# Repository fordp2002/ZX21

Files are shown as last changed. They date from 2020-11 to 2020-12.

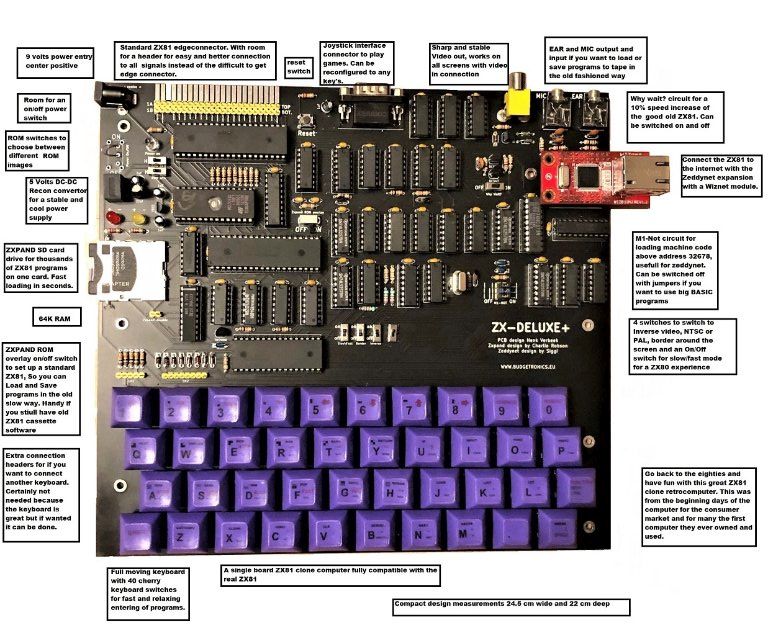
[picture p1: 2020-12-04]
Datasheets/Misc/zxdeluxe metb tekst klein formaat.jpg

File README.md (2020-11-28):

# ZX21
40 Years after the Sinclair ZX81 was released this project aims to preserve the first 4 chip computer

This a computer presevation project for the [Sinclair ZX81](https://github.com/fordp2002/ZX21.git).

Features (Hopefully).

* Drop in replacement for a ZX81
* Built in 16K+ RAM, no need for a RAM Pack
* Built in Composite Video Output 
* Barrel Jack power input, center Positive
* OPTION: Single Joystick port (not compatible with quickfire etc.)
* OPTION: Switchable to 1K RAM
* OPTION: [Back Porch Support](http://zx.zigg.net/misc-projects/ZX81_Video_Conditioning.pdf) for early ULAs
* OPTION: Built in support for [ZX-Wespi](https://github.com/holmatic/zx-iot-mi)
* OPTION: [ZON-X](http://www.zx81stuff.org.uk/zx81/hardware/ZONX81) Compatible Yamaha YM2149F Based Sound
* OPTION: Switchable between Sinclair ROM OR [AT28C256 EEPROM](http://ww1.microchip.com/downloads/en/DeviceDoc/doc0006.pdf)
* OPTION: 16 Pin Box Header for DK'Tronics Keyboard

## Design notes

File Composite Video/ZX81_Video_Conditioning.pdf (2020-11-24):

ZX81 Video Conditioning | http://zx.zigg.net

# ZX81 Video Conditioning

# 1. Introduction

Presented below are two electronic circuits that can be used to improve the video output of the ZX81 ULA, in particular those that do not generate a period of black level voltage (the back porch) following each line synchronisation pulse.

### This document complements a video presentation, in which the operation of each circuit is

described. A link to this video can be found at http://zx.zigg.net.

# 2. All Discrete Transistor Circuit

## 2.1. Circuit Diagram

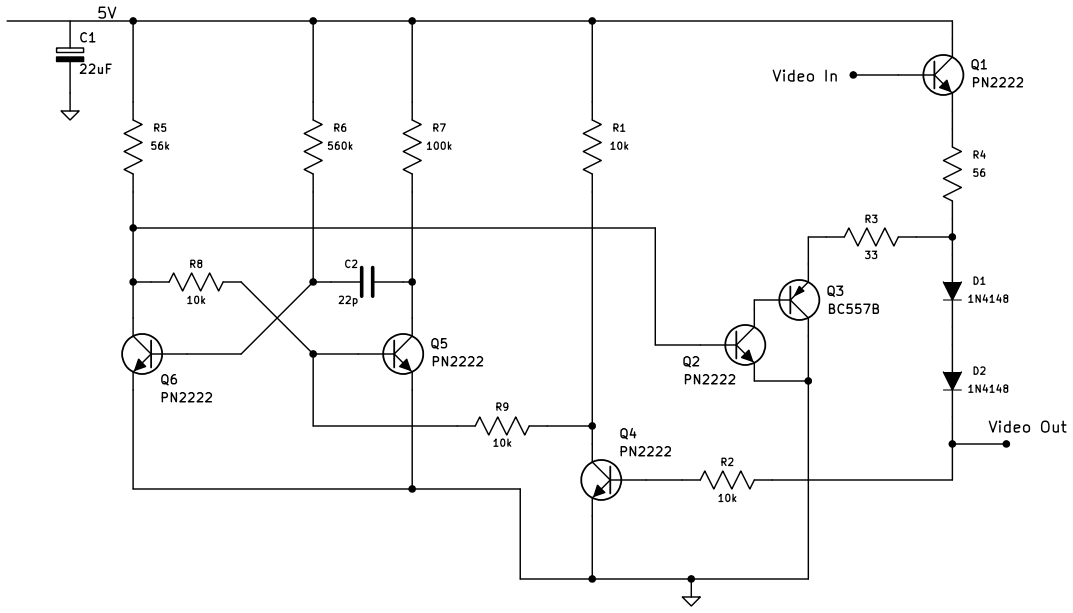
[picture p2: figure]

© Copyright 2015 Ziggurat Communications Ltd. | Version 1.0 | Page 1

# 3. 555-Based Circuit

## 3.1. Circuit Diagram

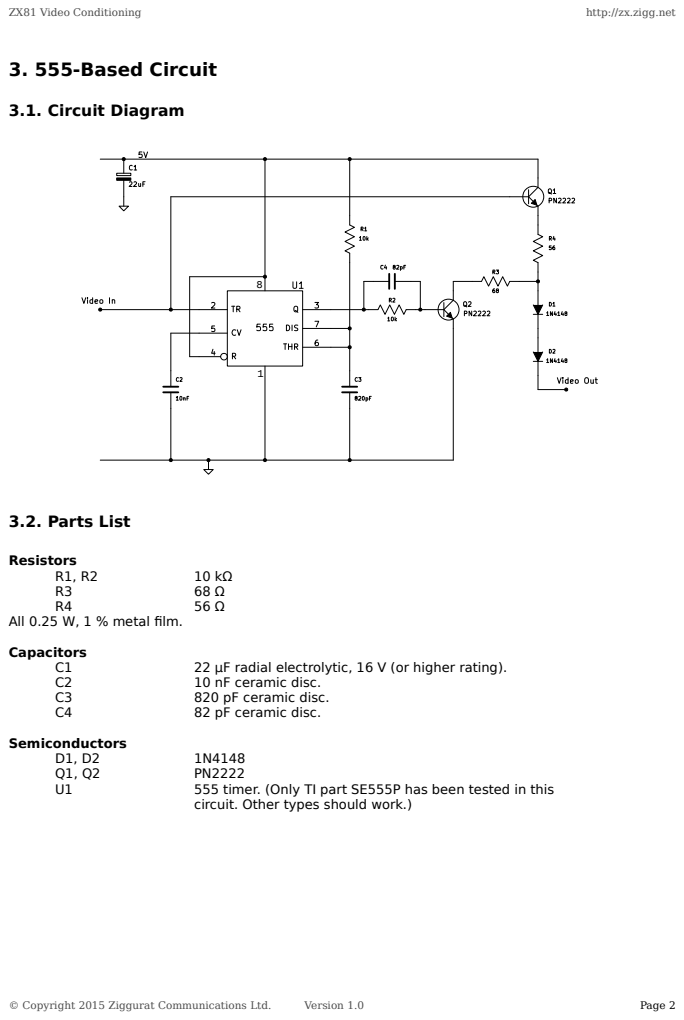
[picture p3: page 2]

circuit. Other types should work.)

## 3.3. Stripboard Layout

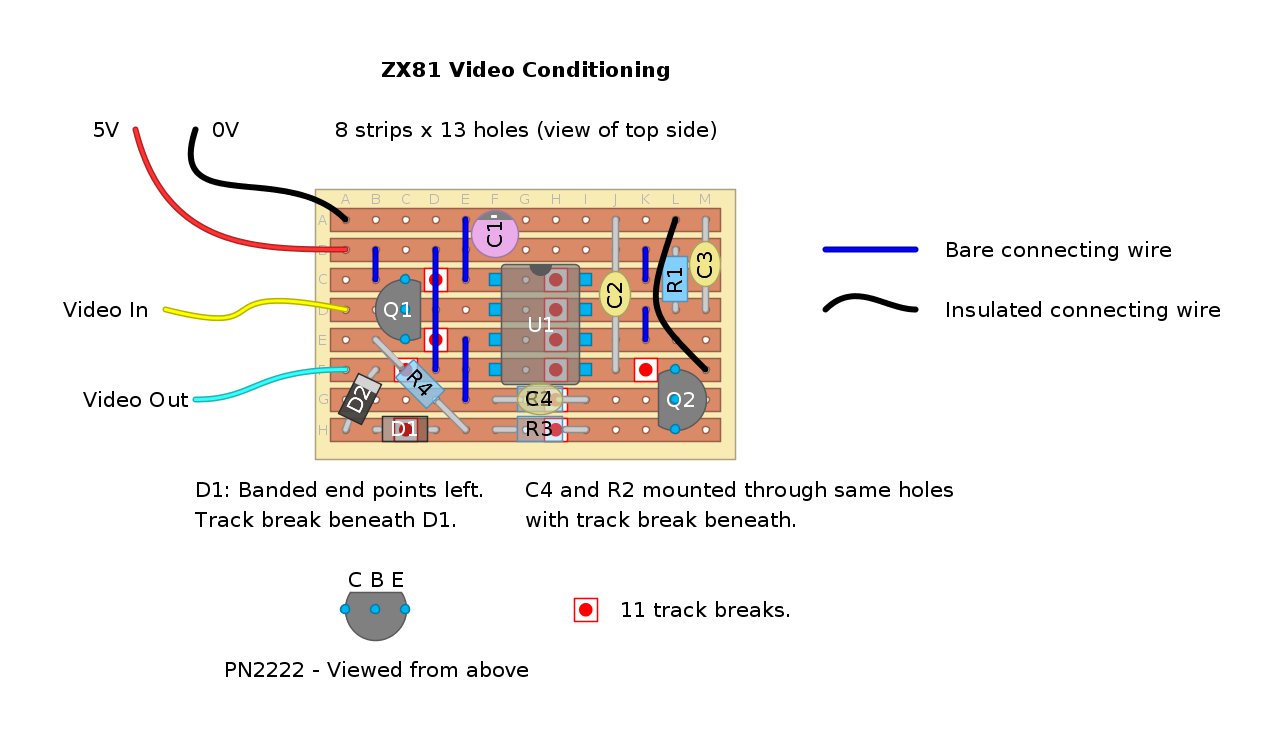
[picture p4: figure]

### CAUTION: The pin-out of most PN2222 transistors is as shown above. However, some have the

positions of their collector and emitter swapped.

The stripboard layout graphic was created using DIY Layout Creator (DIYLC).

This document © Copyright 2015 Ziggurat Communications Ltd. This document may be freely copied, distributed and modified provided this copyright notice is not removed. Modified versions must clearly indicate they have been modified. Portions of this document may be used in other works provided the portions are clearly attributed to Ziggurat Communications Ltd or/and http://zx.zigg.net. This notice does not apply to any elements of this document not created by Ziggurat Communications Ltd.

© Copyright 2015 Ziggurat Communications Ltd. | Version 1.0 | Page 3

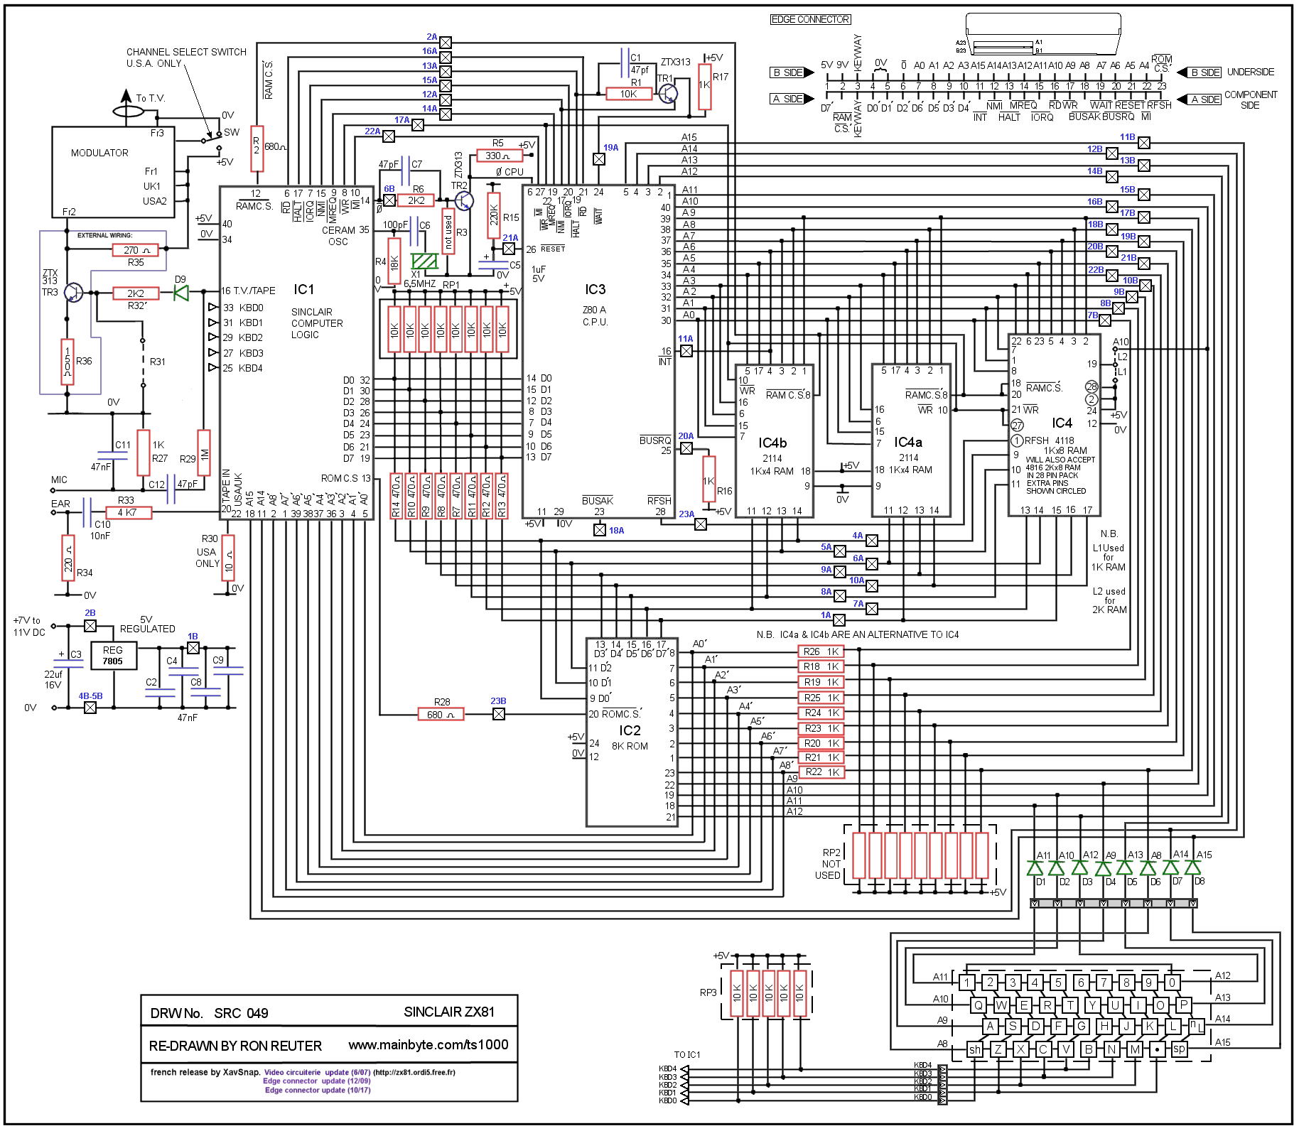
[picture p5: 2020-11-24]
Schematic/schema_ZX81_Fr.gif

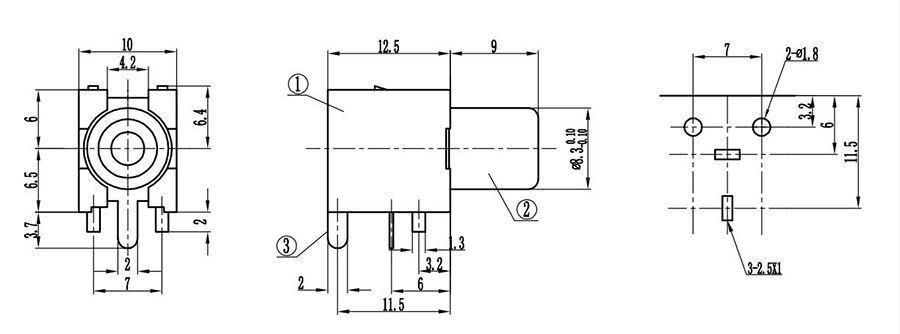
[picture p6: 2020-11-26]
Schematic/Yellow RCA Socket.jpg

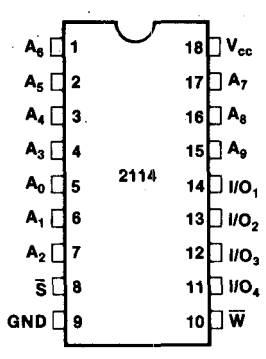
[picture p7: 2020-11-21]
Datasheets/RAM/2114 SRAM pin-out.png

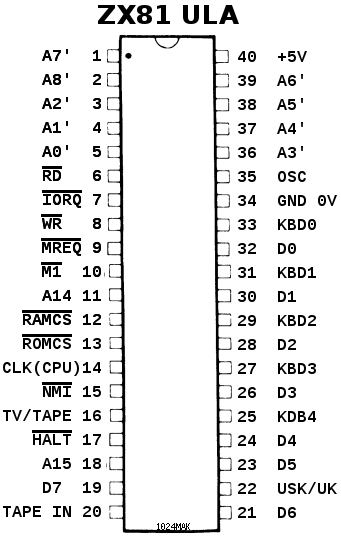
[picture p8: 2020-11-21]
Datasheets/ULA/ZX81 ULA.png

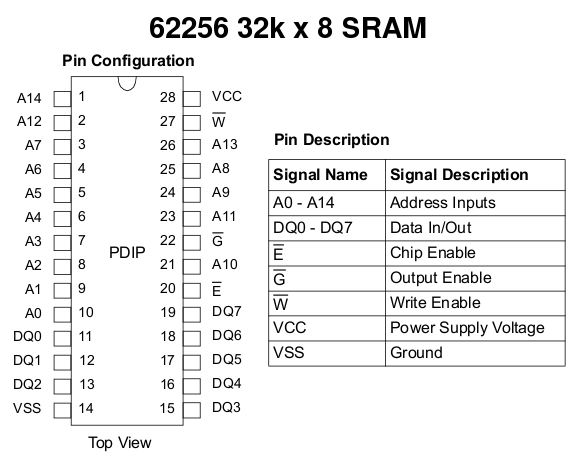
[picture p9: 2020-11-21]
Datasheets/RAM/62256 32k SRAM pin-out.png

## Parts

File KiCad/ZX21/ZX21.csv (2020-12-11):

Id | Designator | Package | Quantity | Designation | Supplier and ref
1 | REF*** | OSHW-Logo2_7.3x6mm_SilkScreen | 1 | OSHW-Logo2_7.3x6mm_SilkScreen
2 | REF*** | OSHW-Logo2_7.3x6mm_Copper | 1 | OSHW-Logo2_7.3x6mm_Copper
3 | MIC1,EAR1 | ASJ_125_3_3.5mm_Jack | 2 | Audio-Jack-3
4 | C101,C302 | CP_Radial_D5.0mm_P2.50mm | 2 | 22U
5 | IC301 | TO-220-3_Vertical | 1 | 3V3 PSU
6 | C303 | C_0603_HandSoldering | 1 | 10N
7 | X1 | Resonator-3pin_w7.0mm_h2.5mm | 1 | 3.5MHz
8 | J701 | Pin_Header_Straight_2x23_Pitch2.54mm | 1 | Conn_02x23_Row_Letter_First
9 | REF** | MountingHole_2.7mm | 1 | MountingHole_2.7mm
10 | J302,J204,J203,J101 | Pin_Header_Straight_1x03_Pitch2.54mm | 4 | Conn_01x03
11 | S1 | EG4208 | 1 | EG4208A
12 | J504,J503,J502 | Pin_Header_Straight_1x08_Pitch2.54mm | 3 | Conn_01x08
13 | C301 | CP_Radial_D5.0mm_P2.50mm | 1 | 47U 25V
14 | C5 | CP_Radial_D5.0mm_P2.50mm | 1 | 1U
15 | C3 | CP_Axial_L11.0mm_D5.0mm_P18.00mm_Horizontal | 1 | 22uF
16 | C501,C9,C4 | C_Disc_D4.7mm_W2.5mm_P5.00mm | 3 | 100N
17 | C104 | C_Disc_D4.7mm_W2.5mm_P5.00mm | 1 | 82P
18 | C103 | C_Disc_D4.7mm_W2.5mm_P5.00mm | 1 | 820P
19 | C102,C10,C8 | C_Disc_D4.7mm_W2.5mm_P5.00mm | 3 | 10N
20 | C12,C7 | C_Disc_D4.7mm_W2.5mm_P5.00mm | 2 | 47P
21 | C11 | C_Disc_D4.7mm_W2.5mm_P5.00mm | 1 | 47N
22 | C6 | C_Disc_D4.7mm_W2.5mm_P5.00mm | 1 | 100P
23 | C1 | C_Disc_D3.0mm_W2.0mm_P2.50mm | 1 | 47P
24 | R504,R301,R201,R27,R26,R25,R24,R23,R22,R21,R20,R19,R18,R17,R16 | R_Axial_DIN0204_L3.6mm_D1.6mm_P7.62mm_Horizontal | 15 | 1K
25 | R503,R502,R501,R302,R33 | R_Axial_DIN0204_L3.6mm_D1.6mm_P7.62mm_Horizontal | 5 | 4K7
26 | R401,R102,R101,R1 | R_Axial_DIN0204_L3.6mm_D1.6mm_P7.62mm_Horizontal | 4 | 10K
27 | R303 | R_Axial_DIN0204_L3.6mm_D1.6mm_P7.62mm_Horizontal | 1 | 100R
28 | IC801 | DIP-4_W15.24mm_Socket_LongPads | 1 | AS6C4008Extra
29 | D102,D101,D8,D7,D6,D5,D4,D3,D2,D1 | D_DO-35_SOD27_P7.62mm_Horizontal | 10 | 1N4148
30 | R104 | R_Axial_DIN0204_L3.6mm_D1.6mm_P7.62mm_Horizontal | 1 | 56R
31 | R103 | R_Axial_DIN0204_L3.6mm_D1.6mm_P7.62mm_Horizontal | 1 | 68R
32 | R34 | R_Axial_DIN0204_L3.6mm_D1.6mm_P7.62mm_Horizontal | 1 | 220R
33 | R30 | R_Axial_DIN0204_L3.6mm_D1.6mm_P7.62mm_Horizontal | 1 | 10R
34 | R29 | R_Axial_DIN0204_L3.6mm_D1.6mm_P7.62mm_Horizontal | 1 | 1M
35 | R28,R2 | R_Axial_DIN0204_L3.6mm_D1.6mm_P7.62mm_Horizontal | 2 | 680R
36 | R15 | R_Axial_DIN0204_L3.6mm_D1.6mm_P7.62mm_Horizontal | 1 | 220K
37 | R14,R13,R12,R11,R10,R9,R8,R7 | R_Axial_DIN0204_L3.6mm_D1.6mm_P7.62mm_Horizontal | 8 | 470R
38 | R6 | R_Axial_DIN0204_L3.6mm_D1.6mm_P7.62mm_Horizontal | 1 | 2K2
39 | R5 | R_Axial_DIN0204_L3.6mm_D1.6mm_P7.62mm_Horizontal | 1 | 330R
40 | R4 | R_Axial_DIN0204_L3.6mm_D1.6mm_P7.62mm_Horizontal | 1 | 18K
41 | IC503 | DIP-16_W7.62mm_Socket_LongPads | 1 | YMZ284
42 | IC4 | DIP-28_W15.24mm_Socket_LongPads | 1 | 62256
43 | R106,R105 | R_0603_HandSoldering | 2 | 10K
44 | IC501 | DIP-40_W15.24mm_Socket_LongPads | 1 | YM2149
45 | IC3 | DIP-40_W15.24mm_Socket_LongPads | 1 | Z80A
46 | IC1 | DIP-40_W15.24mm_Socket_LongPads | 1 | ULA 2C210E
47 | IC2 | DIP-28_W15.24mm_Socket_LongPads | 1 | AT28C256
48 | IC303 | SOT-23_Handsoldering | 1 | AZ1117-3.3
49 | IC502 | DIP-20_W7.62mm_Socket_LongPads | 1 | GAL16V8
50 | J501 | Pin_Header_Straight_1x06_Pitch2.54mm | 1 | Conn_01x06
51 | REF**,REF**,REF**,REF**,REF** | MountingHole_3mm | 5 | MountingHole_3mm
52 | C105 | C_0603_HandSoldering | 1 | 100N
53 | IC102 | SOIC-14_3.9x8.7mm_Pitch1.27mm | 1 | 74HCT00
54 | IC302 | ESP32-WROOM | 1 | ESP32-WROOM
55 | C2 | C_Disc_D5.0mm_W2.5mm_P2.50mm | 1 | 100N
56 | EDGE1 | ZX_Bus_Edge_Connector | 1 | ZX81BUS
57 | IC101 | DIP-8_W7.62mm_Socket_LongPads | 1 | 555
58 | J1 | BARREL_JACK | 1 | Jack-DC
59 | J301 | Pin_Header_Straight_1x04_Pitch2.54mm | 1 | Conn_01x04
60 | J401 | DB9MC | 1 | DB9_Male
61 | J601 | IDC_Header_Straight_16pins | 1 | Conn_02x08_Odd_Even
62 | J702,J703 | Pin_Header_Straight_1x09_Pitch2.54mm | 2 | Conn_01x09
63 | KB1 | Pin_Header_Straight_1x05_Pitch2.54mm | 1 | Conn_01x05
64 | KB2 | Pin_Header_Straight_1x08_Pitch2.54mm | 1 | Conn_01x08
65 | TR403,TR401,TR402,TR404,TR405 | TO-92_Molded_Narrow | 5 | 2N3904
66 | REG1 | TO-220-3_Horizontal | 1 | L7805
67 | RP1 | R_Array_SIP9 | 1 | 10K
68 | RP3 | R_Array_SIP6 | 1 | 10K
69 | TR1,TR2 | TO-92_Molded_Narrow | 2 | BC548
70 | TR101,TR102 | TO-92_Molded_Narrow | 2 | PN2222
71 | VIDEO1 | YELLOW_RCA | 1 | CVBS

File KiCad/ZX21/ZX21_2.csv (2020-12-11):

Reference | Quantity | Value | Footprint | Datasheet | Description | Height | Manufacturer_Name | Manufacturer_Part_Number | Mouser Part Number | Mouser Price/Stock
C1 | 1 | 47P | Capacitors_THT:C_Disc_D3.0mm_W2.0mm_P2.50mm
C8 C10 C102 | 3 | 10N | Capacitors_ThroughHole:C_Disc_D4.7mm_W2.5mm_P5.00mm
C101 C302 | 2 | 22U | Capacitors_ThroughHole:CP_Radial_D5.0mm_P2.50mm
C103 | 1 | 820P | Capacitors_ThroughHole:C_Disc_D4.7mm_W2.5mm_P5.00mm
C104 | 1 | 82P | Capacitors_ThroughHole:C_Disc_D4.7mm_W2.5mm_P5.00mm
C105 | 1 | 100N | Capacitors_SMD:C_0603_HandSoldering
C11 | 1 | 47N | Capacitors_ThroughHole:C_Disc_D4.7mm_W2.5mm_P5.00mm
C2 | 1 | 100N | Capacitors_THT:C_Disc_D5.0mm_W2.5mm_P2.50mm
C3 | 1 | 22uF | Capacitors_ThroughHole:CP_Axial_L11.0mm_D5.0mm_P18.00mm_Horizontal
C301 | 1 | 47U 25V | Capacitors_ThroughHole:CP_Radial_D5.0mm_P2.50mm
C303 | 1 | 10N | Capacitors_SMD:C_0603_HandSoldering
C5 | 1 | 1U | Capacitors_ThroughHole:CP_Radial_D5.0mm_P2.50mm
C6 | 1 | 100P | Capacitors_ThroughHole:C_Disc_D4.7mm_W2.5mm_P5.00mm
C7 C12 | 2 | 47P | Capacitors_ThroughHole:C_Disc_D4.7mm_W2.5mm_P5.00mm
C4 C9 C501 | 3 | 100N | Capacitors_ThroughHole:C_Disc_D4.7mm_W2.5mm_P5.00mm
D1 D2 D3 D4 D5 D6 D7 D8 D101 D102 | 10 | 1N4148 | zxbus:D_DO-35_SOD27_P7.62mm_Horizontal | http://www.nxp.com/documents/data_sheet/1N4148_1N4448.pdf
EDGE1 | 1 | ZX81BUS | zxbus:ZX_Bus_Edge_Connector
IC1 | 1 | ULA 2C210E | zxbus:DIP-40_W15.24mm_Socket_LongPads
IC101 | 1 | 555 | Housings_DIP:DIP-8_W7.62mm_Socket_LongPads | http://www.ti.com/lit/ds/symlink/tlc555.pdf
IC102 | 1 | 74HCT00 | Housings_SOIC:SOIC-14_3.9x8.7mm_Pitch1.27mm | http://www.ti.com/lit/gpn/sn74hct00
IC2 | 1 | AT28C256 | zxbus:DIP-28_W15.24mm_Socket_LongPads
IC3 | 1 | Z80A | zxbus:DIP-40_W15.24mm_Socket_LongPads | www.zilog.com/manage_directlink.php?filepath=docs/z80/um0080
IC301 | 1 | 3V3 PSU | TO_SOT_Packages_THT:TO-220-3_Vertical | http://www.st.com/content/ccc/resource/technical/document/datasheet/41/4f/b3/b0/12/d4/47/88/CD00000444.pdf/files/CD00000444.pdf/jcr:content/translations/en.CD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
IC302 | 1 | ESP32-WROOM | ESP32-footprints-Lib:ESP32-WROOM
IC303 | 1 | AZ1117-3.3 | TO_SOT_Packages_SMD:SOT-23_Handsoldering | https://www.diodes.com/assets/Datasheets/AZ1117.pdf
IC4 | 1 | 62256 | zxbus:DIP-28_W15.24mm_Socket_LongPads
IC501 | 1 | YM2149 | zxbus:DIP-40_W15.24mm_Socket_LongPads
IC502 | 1 | GAL16V8 | Housings_DIP:DIP-20_W7.62mm_Socket_LongPads
IC503 | 1 | YMZ284 | Housings_DIP:DIP-16_W7.62mm_Socket_LongPads
IC801 | 1 | AS6C4008Extra | zxbus:DIP-4_W15.24mm_Socket_LongPads
J1 | 1 | Jack-DC | Connect:BARREL_JACK | ~
J101 J203 J204 J302 | 4 | Conn_01x03 | zxbus:Pin_Header_Straight_1x03_Pitch2.54mm | ~
J301 | 1 | Conn_01x04 | Pin_Headers:Pin_Header_Straight_1x04_Pitch2.54mm | ~
J401 | 1 | DB9_Male | Connectors:DB9MC
J501 | 1 | Conn_01x06 | Pin_Headers:Pin_Header_Straight_1x06_Pitch2.54mm | ~
J502 J503 J504 | 3 | Conn_01x08 | zxbus:Pin_Header_Straight_1x08_Pitch2.54mm | ~
J601 | 1 | Conn_02x08_Odd_Even | Connectors:IDC_Header_Straight_16pins | ~
J701 | 1 | Conn_02x23_Row_Letter_First | zxbus:Pin_Header_Straight_2x23_Pitch2.54mm | ~
J702 J703 | 2 | Conn_01x09 | Pin_Headers:Pin_Header_Straight_1x09_Pitch2.54mm | ~
KB1 | 1 | Conn_01x05 | Pin_Headers:Pin_Header_Straight_1x05_Pitch2.54mm | ~
KB2 | 1 | Conn_01x08 | Pin_Headers:Pin_Header_Straight_1x08_Pitch2.54mm | ~
MIC1 EAR1 | 2 | Audio-Jack-3 | zxbus:ASJ_125_3_3.5mm_Jack | ~
R1 R101 R102 R401 | 4 | 10K | Resistors_ThroughHole:R_Axial_DIN0204_L3.6mm_D1.6mm_P7.62mm_Horizontal
R7 R8 R9 R10 R11 R12 R13 R14 | 8 | 470R | Resistors_ThroughHole:R_Axial_DIN0204_L3.6mm_D1.6mm_P7.62mm_Horizontal
R103 | 1 | 68R | Resistors_ThroughHole:R_Axial_DIN0204_L3.6mm_D1.6mm_P7.62mm_Horizontal
R104 | 1 | 56R | Resistors_ThroughHole:R_Axial_DIN0204_L3.6mm_D1.6mm_P7.62mm_Horizontal
R105 R106 | 2 | 10K | Resistors_SMD:R_0603_HandSoldering
R15 | 1 | 220K | Resistors_ThroughHole:R_Axial_DIN0204_L3.6mm_D1.6mm_P7.62mm_Horizontal
R2 R28 | 2 | 680R | Resistors_ThroughHole:R_Axial_DIN0204_L3.6mm_D1.6mm_P7.62mm_Horizontal
R16 R17 R18 R19 R20 R21 R22 R23 R24 R25 R26 R27 R201 R301 R504 | 15 | 1K | Resistors_ThroughHole:R_Axial_DIN0204_L3.6mm_D1.6mm_P7.62mm_Horizontal
R29 | 1 | 1M | Resistors_ThroughHole:R_Axial_DIN0204_L3.6mm_D1.6mm_P7.62mm_Horizontal
R30 | 1 | 10R | Resistors_ThroughHole:R_Axial_DIN0204_L3.6mm_D1.6mm_P7.62mm_Horizontal
R303 | 1 | 100R | Resistors_ThroughHole:R_Axial_DIN0204_L3.6mm_D1.6mm_P7.62mm_Horizontal
R33 R302 R501 R502 R503 | 5 | 4K7 | Resistors_ThroughHole:R_Axial_DIN0204_L3.6mm_D1.6mm_P7.62mm_Horizontal
R34 | 1 | 220R | Resistors_ThroughHole:R_Axial_DIN0204_L3.6mm_D1.6mm_P7.62mm_Horizontal
R4 | 1 | 18K | Resistors_ThroughHole:R_Axial_DIN0204_L3.6mm_D1.6mm_P7.62mm_Horizontal
R5 | 1 | 330R | Resistors_ThroughHole:R_Axial_DIN0204_L3.6mm_D1.6mm_P7.62mm_Horizontal
R6 | 1 | 2K2 | Resistors_ThroughHole:R_Axial_DIN0204_L3.6mm_D1.6mm_P7.62mm_Horizontal
REG1 | 1 | L7805 | TO_SOT_Packages_THT:TO-220-3_Horizontal | http://www.st.com/content/ccc/resource/technical/document/datasheet/41/4f/b3/b0/12/d4/47/88/CD00000444.pdf/files/CD00000444.pdf/jcr:content/translations/en.CD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
RP1 | 1 | 10K | Resistors_THT:R_Array_SIP9 | http://www.vishay.com/docs/31509/csc.pdf
RP3 | 1 | 10K | Resistors_THT:R_Array_SIP6 | http://www.vishay.com/docs/31509/csc.pdf
S1 | 1 | EG4208A | SamacSys_Parts:EG4208 | https://www.e-switch.com/system/asset/product_line/data_sheet/119/EG.pdf | Slide Switches 4P2T SIDE OP PC MNT | 5 | E-Switch | EG4208A | 612-EG4208A | https://www.mouser.co.uk/ProductDetail/E-Switch/EG4208A?qs=01kh3H%252BlXijiZ%252BDtLjJDLw%3D%3D
TR101 TR102 | 2 | PN2222 | TO_SOT_Packages_THT:TO-92_Molded_Narrow | http://www.fairchildsemi.com/ds/PN/PN2222A.pdf
TR1 TR2 | 2 | BC548 | TO_SOT_Packages_THT:TO-92_Molded_Narrow | http://www.fairchildsemi.com/ds/BC/BC547.pdf
TR401 TR402 TR403 TR404 TR405 | 5 | 2N3904 | TO_SOT_Packages_THT:TO-92_Molded_Narrow | https://www.fairchildsemi.com/datasheets/2N/2N3904.pdf
VIDEO1 | 1 | CVBS | zxbus:YELLOW_RCA
X1 | 1 | 3.5MHz | Crystals:Resonator-3pin_w7.0mm_h2.5mm

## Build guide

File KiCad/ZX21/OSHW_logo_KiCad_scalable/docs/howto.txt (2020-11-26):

How to make your own:
---------------------

Watch / read this first:

* http://www.kicad-pcb.org/display/KICAD/Videos+by+zupnikal

The last two videos should be helpful for how to create a custom .emp file from images.

* http://www.re-innovation.co.uk/web12/index.php/en/blog-75/230-adding-logo-to-kicad

If you use linux (which you should), you don't have to use the online-scaler. Just use the scripts!

---

* Create a folder to hold your new footprint library.
* Copy the scripts 'make_lib.sh' and 'scale.pl' into that folder.
* Make sure these files are executable (chmod u+x ...).
* Copy your custom .emp file into that foler.

* Run the 'make_lib.sh' script as follows:

./make_lib.sh input-file.emp lib-name.mod START END

START and END are placeholders for positive integer numbers (1,2,3...) that determine
the range of created footprint sizes. The units are metric (mm).

The 'lib-name.mod' file will show up in the 'lib' sub-folder. Add it to your pcbnew
library settings as usual.

Footprints that are created for back-layers are automagically mirrored horizontally.
To place them onto a back-layer, hover the mouse-pointer over them and press 'f' for 'flip'.

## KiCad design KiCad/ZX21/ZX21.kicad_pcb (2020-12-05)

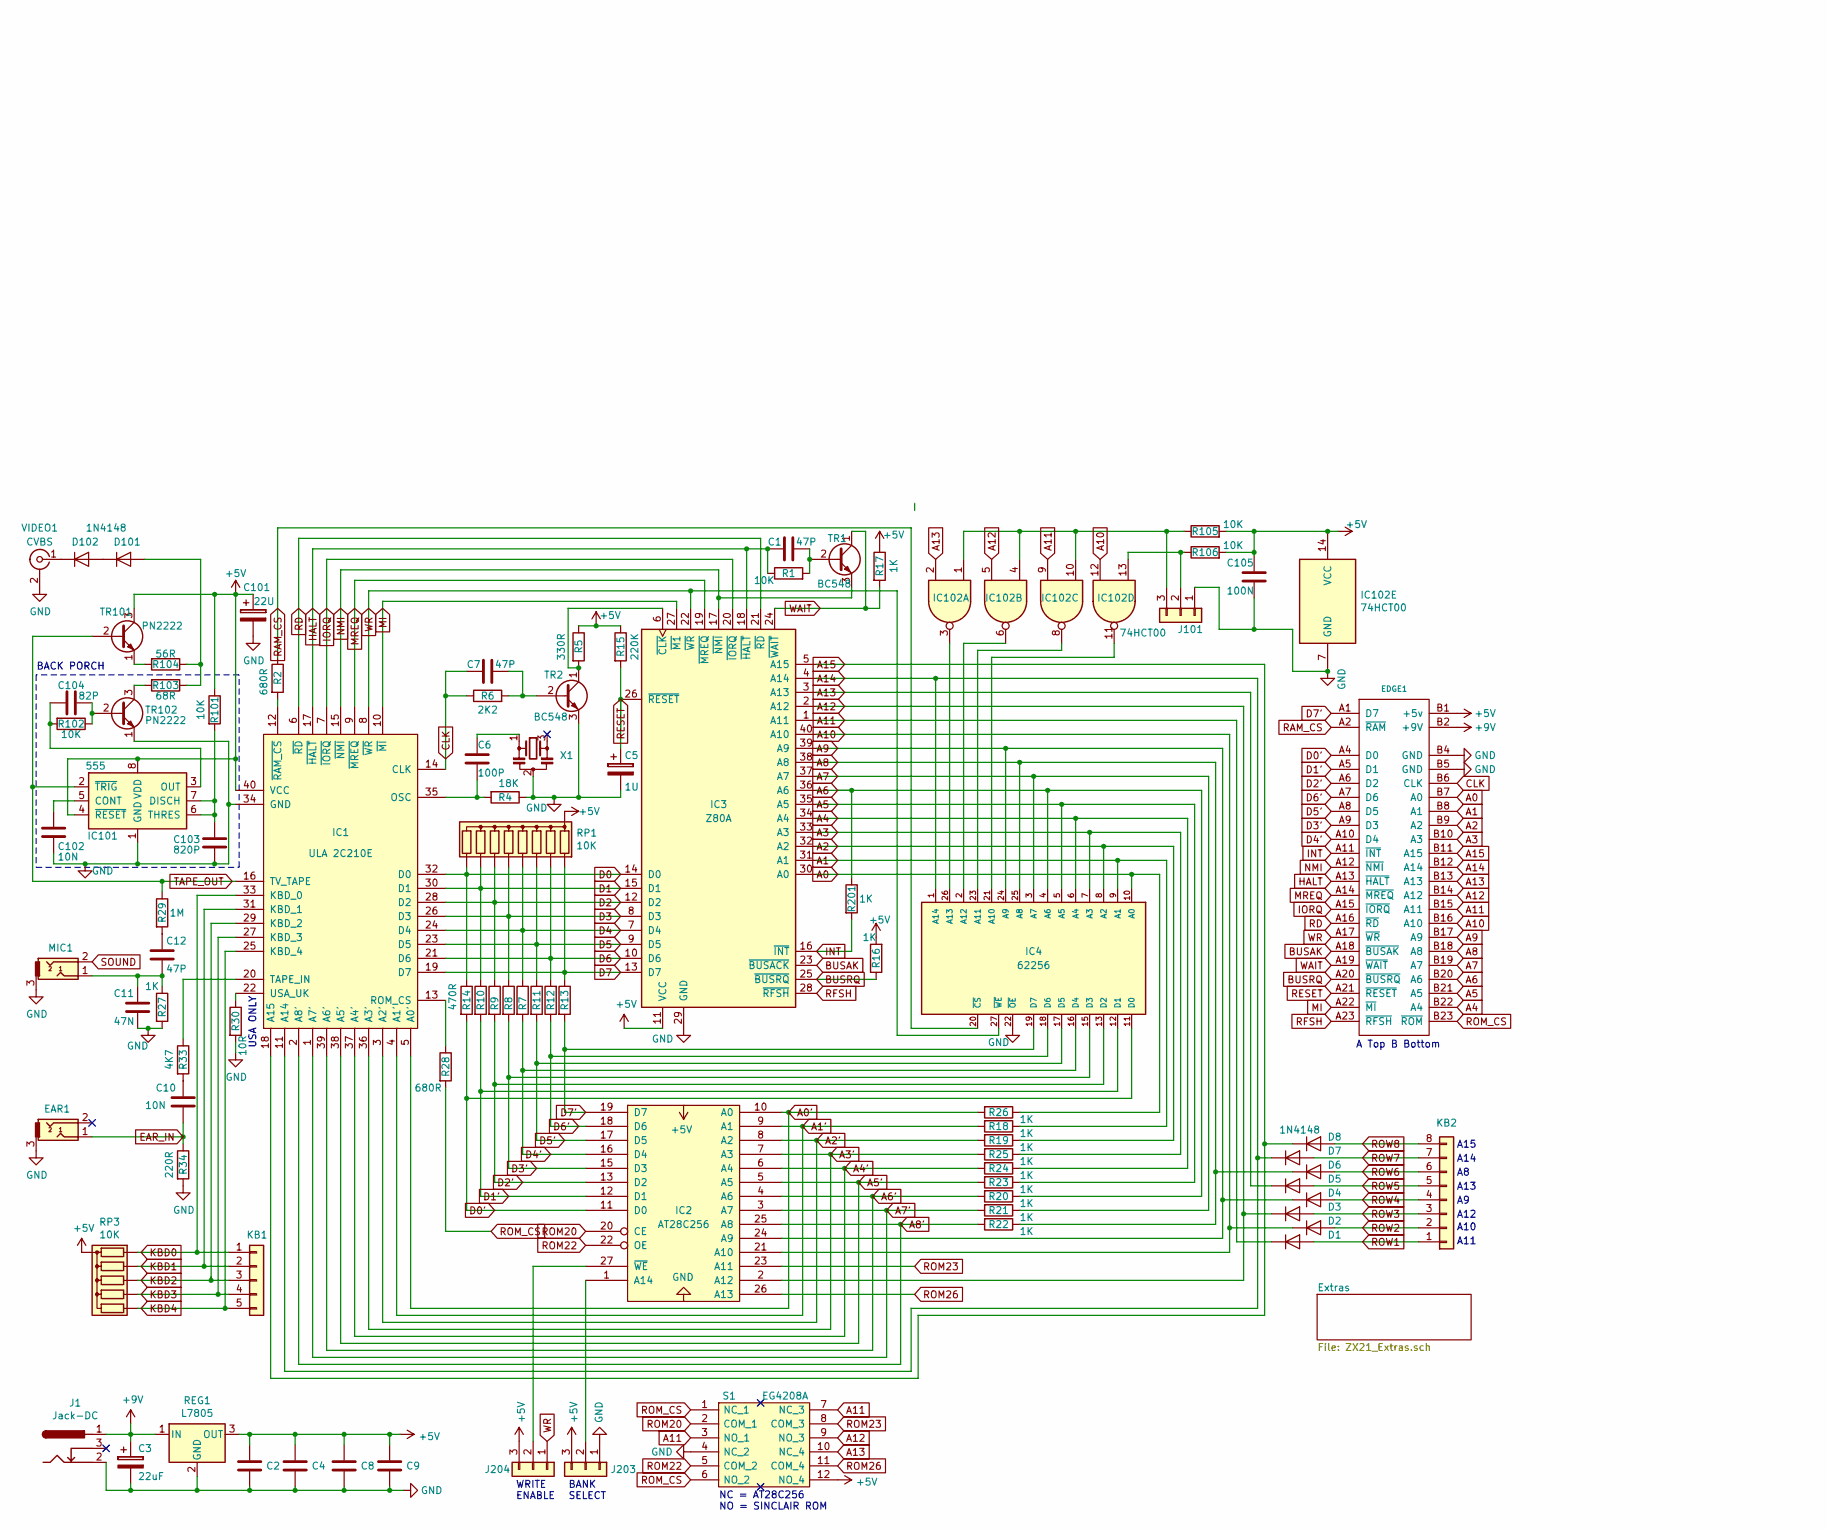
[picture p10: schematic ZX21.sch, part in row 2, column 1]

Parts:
C1: 47P; C_Disc_D3.0mm_W2.0mm_P2.50mm
C2: 100N; C_Disc_D5.0mm_W2.5mm_P2.50mm
C3: 22uF; CP_Axial_L11.0mm_D5.0mm_P18.00mm_Horizontal
C4, C9: 100N; C_Disc_D4.7mm_W2.5mm_P5.00mm
C5: 1U; CP_Radial_D5.0mm_P2.50mm
C6: 100P; C_Disc_D4.7mm_W2.5mm_P5.00mm
C7, C12: 47P; C_Disc_D4.7mm_W2.5mm_P5.00mm
C8, C10, C102: 10N; C_Disc_D4.7mm_W2.5mm_P5.00mm
C11: 47N; C_Disc_D4.7mm_W2.5mm_P5.00mm
C101: 22U; CP_Radial_D5.0mm_P2.50mm
C103: 820P; C_Disc_D4.7mm_W2.5mm_P5.00mm
C104: 82P; C_Disc_D4.7mm_W2.5mm_P5.00mm
C105: 100N; C_0603_HandSoldering
D1, D2, D3, D4, D5, D6, D7, D8, D101, D102: 1N4148; D_DO-35_SOD27_P7.62mm_Horizontal
EAR1: Audio-Jack-3; ASJ_125_3_3.5mm_Jack
EDGE1: ZX81BUS; ZX_Bus_Edge_Connector
IC1: ULA 2C210E; DIP-40_W15.24mm_Socket_LongPads
IC2: AT28C256; DIP-28_W15.24mm_Socket_LongPads
IC3: Z80A; DIP-40_W15.24mm_Socket_LongPads
IC4: 62256; DIP-28_W15.24mm_Socket_LongPads
IC101: 555; DIP-8_W7.62mm_Socket_LongPads
IC102: 74HCT00; SOIC-14_3.9x8.7mm_Pitch1.27mm
J1: Jack-DC; BARREL_JACK
J101, J203, J204: Conn_01x03; Pin_Header_Straight_1x03_Pitch2.54mm
KB1: Conn_01x05; Pin_Header_Straight_1x05_Pitch2.54mm
KB2: Conn_01x08; Pin_Header_Straight_1x08_Pitch2.54mm
MIC1: Audio-Jack-3; ASJ_125_3_3.5mm_Jack
R1, R101, R102: 10K; R_Axial_DIN0204_L3.6mm_D1.6mm_P7.62mm_Horizontal
R2, R28: 680R; R_Axial_DIN0204_L3.6mm_D1.6mm_P7.62mm_Horizontal
R4: 18K; R_Axial_DIN0204_L3.6mm_D1.6mm_P7.62mm_Horizontal
R5: 330R; R_Axial_DIN0204_L3.6mm_D1.6mm_P7.62mm_Horizontal
R6: 2K2; R_Axial_DIN0204_L3.6mm_D1.6mm_P7.62mm_Horizontal
R7, R8, R9, R10, R11, R12, R13, R14: 470R; R_Axial_DIN0204_L3.6mm_D1.6mm_P7.62mm_Horizontal
R15: 220K; R_Axial_DIN0204_L3.6mm_D1.6mm_P7.62mm_Horizontal
R16, R17, R18, R19, R20, R21, R22, R23, R24, R25, R26, R27, R201: 1K; R_Axial_DIN0204_L3.6mm_D1.6mm_P7.62mm_Horizontal
R29: 1M; R_Axial_DIN0204_L3.6mm_D1.6mm_P7.62mm_Horizontal
R30: 10R; R_Axial_DIN0204_L3.6mm_D1.6mm_P7.62mm_Horizontal
R33: 4K7; R_Axial_DIN0204_L3.6mm_D1.6mm_P7.62mm_Horizontal
R34: 220R; R_Axial_DIN0204_L3.6mm_D1.6mm_P7.62mm_Horizontal
R103: 68R; R_Axial_DIN0204_L3.6mm_D1.6mm_P7.62mm_Horizontal
R104: 56R; R_Axial_DIN0204_L3.6mm_D1.6mm_P7.62mm_Horizontal
R105, R106: 10K; R_0603_HandSoldering
REG1: L7805; TO-220-3_Horizontal
RP1: 10K; R_Array_SIP9
RP3: 10K; R_Array_SIP6
S1: EG4208A; EG4208; Manufacturer_Part_Number EG4208A; Mouser Part Number 612-EG4208A
TR1, TR2: BC548; TO-92_Molded_Narrow
TR101, TR102: PN2222; TO-92_Molded_Narrow
VIDEO1: CVBS; YELLOW_RCA
X1: 3.5MHz; Resonator-3pin_w7.0mm_h2.5mm

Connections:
+5V: C2.1, C4.1, C8.1, C9.1, C101.1, C105.1, EDGE1.B1 (+5v), IC1.40 (VCC), IC2.28 (VCC), IC3.11 (VCC), IC4.28 (VCC), IC101.4 (~RESET), IC101.8 (VDD), IC102.14 (VCC), J203.3, J204.3, R5.1, R15.1, R16.2, R17.1, R101.1, R105.2, R106.2, REG1.3 (OUT), RP1.1 (common), RP3.1 (common), S1.12 (NO_4), TR101.3 (C); also elsewhere on the board
+9V: C3.1, EDGE1.B2 (+9V), J1.1, REG1.1 (IN); also elsewhere on the board
A0: EDGE1.B7 (A0), IC3.30 (A0), IC4.10 (A0), R26.1; also elsewhere on the board
A0': IC1.5 (A0'), IC2.10 (A0), R26.2; also elsewhere on the board
A1: EDGE1.B8 (A1), IC3.31 (A1), IC4.9 (A1), R18.1; also elsewhere on the board
A1': IC1.4 (A1'), IC2.9 (A1), R18.2; also elsewhere on the board
A2: EDGE1.B9 (A2), IC3.32 (A2), IC4.8 (A2), R19.1; also elsewhere on the board
A2': IC1.3 (A2'), IC2.8 (A2), R19.2; also elsewhere on the board
A3: EDGE1.B10 (A3), IC3.33 (A3), IC4.7 (A3), R25.1; also elsewhere on the board
A3': IC1.36 (A3'), IC2.7 (A3), R25.2; also elsewhere on the board
A4: EDGE1.B22 (A4), IC3.34 (A4), IC4.6 (A4), R24.1; also elsewhere on the board
A4': IC1.37 (A4'), IC2.6 (A4), R24.2; also elsewhere on the board
A5: EDGE1.B21 (A5), IC3.35 (A5), IC4.5 (A5), R23.1; also elsewhere on the board
A5': IC1.38 (A5'), IC2.5 (A5), R23.2; also elsewhere on the board
A6: EDGE1.B20 (A6), IC3.36 (A6), IC4.4 (A6), R20.1, R201.1; also elsewhere on the board
A6': IC1.39 (A6'), IC2.4 (A6), R20.2; also elsewhere on the board
A7: EDGE1.B19 (A7), IC3.37 (A7), IC4.3 (A7), R21.1; also elsewhere on the board
A7': IC1.1 (A7'), IC2.3 (A7), R21.2; also elsewhere on the board
A8: D6.1 (K), EDGE1.B18 (A8), IC3.38 (A8), IC4.25 (A8), R22.1; also elsewhere on the board
A8': IC1.2 (A8'), IC2.25 (A8), R22.2; also elsewhere on the board
A9: D4.1 (K), EDGE1.B17 (A9), IC2.24 (A9), IC3.39 (A9), IC4.24 (A9); also elsewhere on the board
A10: D2.1 (K), EDGE1.B16 (A10), IC2.21 (A10), IC3.40 (A10), IC102.12; also elsewhere on the board
A11: D1.1 (K), EDGE1.B15 (A11), IC3.1 (A11), IC102.9, S1.3 (NO_1), S1.7 (NC_3); also elsewhere on the board
A12: D3.1 (K), EDGE1.B14 (A12), IC2.2 (A12), IC3.2 (A12), IC102.5, S1.9 (NO_3); also elsewhere on the board
A13: D5.1 (K), EDGE1.B13 (A13), IC3.3 (A13), IC102.2, S1.10 (NC_4); also elsewhere on the board
A14: D7.1 (K), EDGE1.B12 (A14), IC1.11 (A14), IC3.4 (A14), IC4.1 (A14); also elsewhere on the board
A15: D8.1 (K), EDGE1.B11 (A15), IC1.18 (A15), IC3.5 (A15); also elsewhere on the board
BUSAK: EDGE1.A18 (~BUSAK), IC3.23 (~BUSACK); also elsewhere on the board
BUSRQ: EDGE1.A20 (~BUSRQ), IC3.25 (~BUSRQ), R16.1; also elsewhere on the board
CLK: C7.2, EDGE1.B6 (CLK), IC1.14 (CLK), R6.1; also elsewhere on the board
D0: IC1.32 (D0), IC3.14 (D0), R14.1, RP1.9 (R8); also elsewhere on the board
D0': EDGE1.A4 (D0), IC2.11 (D0), IC4.11 (D0), R14.2; also elsewhere on the board
D1: IC1.30 (D1), IC3.15 (D1), R10.1, RP1.8 (R7); also elsewhere on the board
D1': EDGE1.A5 (D1), IC2.12 (D1), IC4.12 (D1), R10.2; also elsewhere on the board
D2: IC1.28 (D2), IC3.12 (D2), R9.1, RP1.7 (R6); also elsewhere on the board
D2': EDGE1.A6 (D2), IC2.13 (D2), IC4.13 (D2), R9.2; also elsewhere on the board
D3: IC1.26 (D3), IC3.8 (D3), R8.1, RP1.6 (R5); also elsewhere on the board
D3': EDGE1.A9 (D3), IC2.15 (D3), IC4.15 (D3), R8.2; also elsewhere on the board
D4: IC1.24 (D4), IC3.7 (D4), R7.1, RP1.5 (R4); also elsewhere on the board
D4': EDGE1.A10 (D4), IC2.16 (D4), IC4.16 (D4), R7.2; also elsewhere on the board
D5: IC1.23 (D5), IC3.9 (D5), R11.1, RP1.4 (R3); also elsewhere on the board
D5': EDGE1.A8 (D5), IC2.17 (D5), IC4.17 (D5), R11.2; also elsewhere on the board
D6: IC1.21 (D6), IC3.10 (D6), R12.2, RP1.3 (R2); also elsewhere on the board
D6': EDGE1.A7 (D6), IC2.18 (D6), IC4.18 (D6), R12.1; also elsewhere on the board
D7: IC1.19 (D7), IC3.13 (D7), R13.1, RP1.2 (R1); also elsewhere on the board
D7': EDGE1.A1 (D7), IC2.19 (D7), IC4.19 (D7), R13.2; also elsewhere on the board
EAR_IN: C10.2, EAR1.1, R34.1; also elsewhere on the board
GND: C2.2, C3.2, C4.2, C5.2, C8.2, C9.2, C11.2, C101.2, C102.2, C103.2, C105.2, EAR1.3, EDGE1.B4 (GND), EDGE1.B5 (GND), IC1.34 (GND), IC2.14 (GND), IC3.29 (GND), IC4.14 (GND), IC4.22 (~OE), IC101.1 (GND), IC102.7 (GND), J1.2, J101.1, J203.1, MIC1.3, R4.1, R27.2, R30.2, R34.2, REG1.2 (GND), S1.4 (NC_2), TR2.3 (E), TR102.1 (E), VIDEO1.2 (Ext), X1.2; also elsewhere on the board
HALT: C1.2, EDGE1.A13 (~HALT), IC1.17 (~HALT), IC3.18 (~HALT), R1.1; also elsewhere on the board
INT: EDGE1.A11 (~INT), IC3.16 (~INT), R201.2; also elsewhere on the board
IORQ: EDGE1.A15 (~IORQ), IC1.7 (~IORQ), IC3.20 (~IORQ); also elsewhere on the board
KBD0: IC1.33 (KBD_0), KB1.1, RP3.2 (R1); also elsewhere on the board
KBD1: IC1.31 (KBD_1), KB1.2, RP3.3 (R2); also elsewhere on the board
KBD2: IC1.29 (KBD_2), KB1.3, RP3.4 (R3); also elsewhere on the board
KBD3: IC1.27 (KBD_3), KB1.4, RP3.5 (R4); also elsewhere on the board
KBD4: IC1.25 (KBD_4), KB1.5, RP3.6 (R5); also elsewhere on the board
MI: EDGE1.A22 (~MI), IC1.10 (~MI), IC3.27 (~M1~); also elsewhere on the board
MREQ: EDGE1.A14 (~MREQ), IC1.9 (~MREQ), IC3.19 (~MREQ); also elsewhere on the board
NMI: EDGE1.A12 (~NMI), IC1.15 (~NMI), IC3.17 (~NMI), TR1.3 (E); also elsewhere on the board
unnamed: C1.1, R1.2, TR1.2 (B)
unnamed: C6.1, X1.1
unnamed: C6.2, IC1.35 (OSC), R4.2
unnamed: C7.1, R6.2, TR2.2 (B)
unnamed: C10.1, R33.2
unnamed: C11.1, C12.2, MIC1.1, R27.1
unnamed: C12.1, R29.2
unnamed: C102.1, IC101.5 (CONT)
unnamed: C103.1, IC101.6 (THRES), IC101.7 (DISCH), R101.2
unnamed: C104.1, IC101.3 (OUT), R102.2
unnamed: C104.2, R102.1, TR102.2 (B)
unnamed: D101.1 (K), D102.2 (A)
unnamed: D101.2 (A), R103.1, R104.1
unnamed: D102.1 (K), VIDEO1.1 (In)
unnamed: IC1.12 (~RAM_CS), R2.2
unnamed: IC1.13 (ROM_CS), R28.1
unnamed: IC1.20 (TAPE_IN), R33.1
unnamed: IC1.22 (USA_UK), R30.1
unnamed: IC2.1 (A14), J203.2
unnamed: IC2.27 (~WE), J204.2
unnamed: IC3.6 (~CLK), R5.2, TR2.1 (C)
unnamed: IC102.1, IC102.4, IC102.10, J101.3, R105.1
unnamed: IC4.26 (A13), IC102.3
unnamed: IC4.2 (A12), IC102.6
unnamed: IC4.23 (A11), IC102.8
unnamed: IC4.21 (A10), IC102.11
unnamed: IC102.13, J101.2, R106.1
unnamed: R103.2, TR102.3 (C)
unnamed: R104.2, TR101.1 (E)
RAM_CS: EDGE1.A2 (~RAM), IC4.20 (~CS), R2.1; also elsewhere on the board
RD: EDGE1.A16 (~RD), IC1.6 (~RD), IC3.21 (~RD); also elsewhere on the board
RESET: C5.1, EDGE1.A21 (~RESET), IC3.26 (~RESET), R15.2; also elsewhere on the board
RFSH: EDGE1.A23 (~RFSH), IC3.28 (~RFSH); also elsewhere on the board
ROM20: IC2.20 (CE), S1.2 (COM_1)
ROM22: IC2.22 (OE), S1.5 (COM_2)
ROM23: IC2.23 (A11), S1.8 (COM_3)
ROM26: IC2.26 (A13), S1.11 (COM_4)
ROM_CS: EDGE1.B23 (~ROM), R28.2, S1.1 (NC_1), S1.6 (NO_2); also elsewhere on the board
ROW1: D1.2 (A), KB2.1; also elsewhere on the board
ROW2: D2.2 (A), KB2.2; also elsewhere on the board
ROW3: D3.2 (A), KB2.3; also elsewhere on the board
ROW4: D4.2 (A), KB2.4; also elsewhere on the board
ROW5: D5.2 (A), KB2.5; also elsewhere on the board
ROW6: D6.2 (A), KB2.6; also elsewhere on the board
ROW7: D7.2 (A), KB2.7; also elsewhere on the board
ROW8: D8.2 (A), KB2.8; also elsewhere on the board
SOUND: MIC1.2; also elsewhere on the board
TAPE_OUT: IC1.16 (TV_TAPE), IC101.2 (~TRIG), R29.1, TR101.2 (B); also elsewhere on the board
WAIT: EDGE1.A19 (~WAIT), IC3.24 (~WAIT~), R17.2, TR1.1 (C); also elsewhere on the board
WR: EDGE1.A17 (~WR), IC1.8 (~WR), IC3.22 (~WR), IC4.27 (~WE), J204.1; also elsewhere on the board

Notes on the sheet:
BANK SELECT
WRITE ENABLE
A Top B Bottom
USA ONLY
A11
A10
A12
A13
A14
A15
NC = AT28C256 NO = SINCLAIR ROM
BACK PORCH

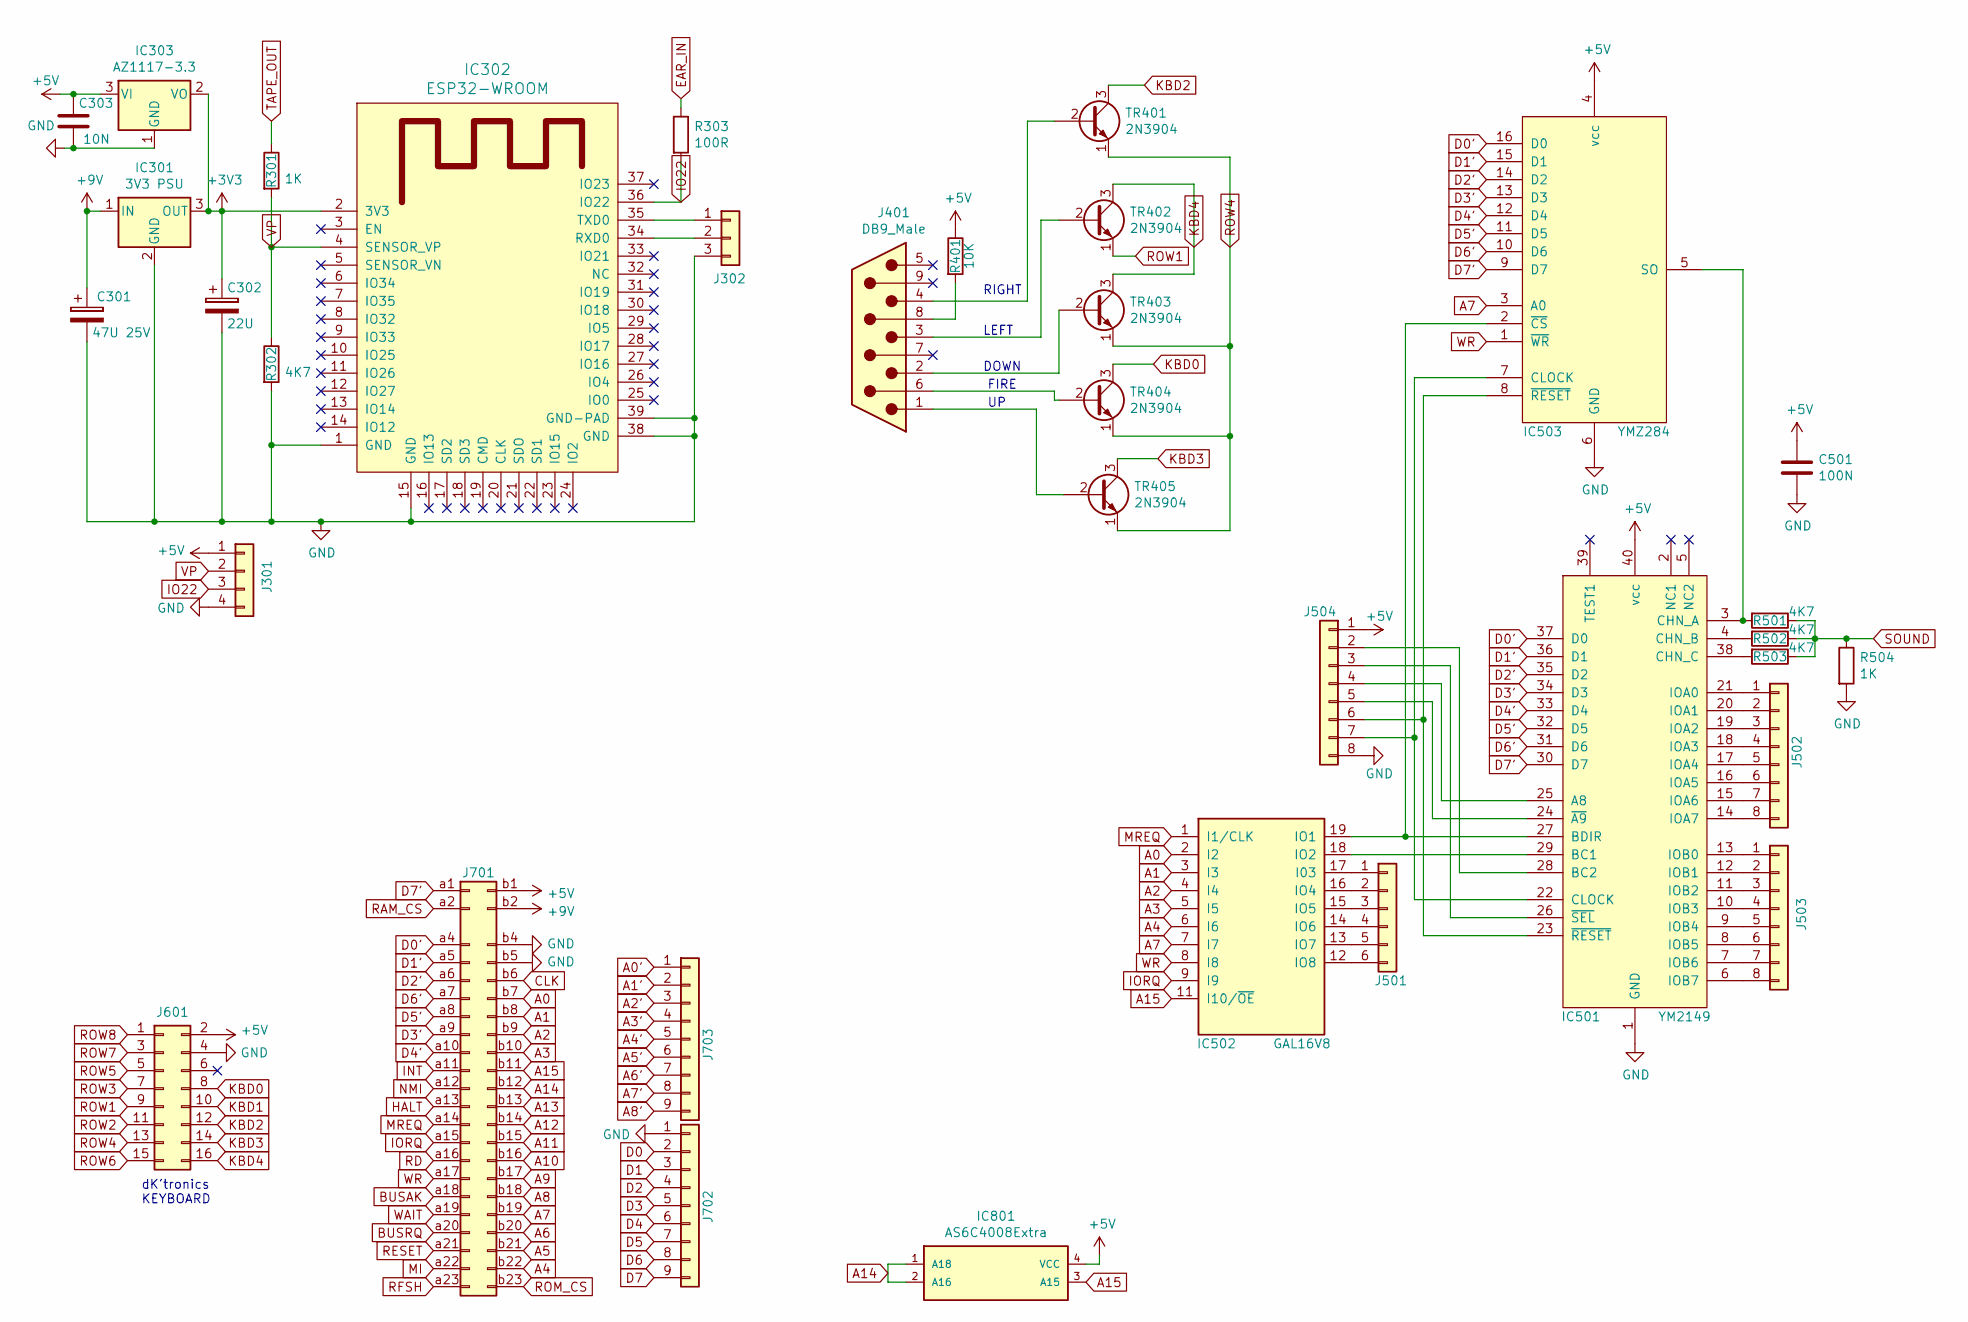
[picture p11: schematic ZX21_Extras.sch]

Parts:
C301: 47U 25V; CP_Radial_D5.0mm_P2.50mm
C302: 22U; CP_Radial_D5.0mm_P2.50mm
C303: 10N; C_0603_HandSoldering
C501: 100N; C_Disc_D4.7mm_W2.5mm_P5.00mm
IC301: 3V3 PSU; TO-220-3_Vertical
IC302: ESP32-WROOM
IC303: AZ1117-3.3; SOT-23_Handsoldering
IC501: YM2149; DIP-40_W15.24mm_Socket_LongPads
IC502: GAL16V8; DIP-20_W7.62mm_Socket_LongPads
IC503: YMZ284; DIP-16_W7.62mm_Socket_LongPads
IC801: AS6C4008Extra; DIP-4_W15.24mm_Socket_LongPads
J301: Conn_01x04; Pin_Header_Straight_1x04_Pitch2.54mm
J302: Conn_01x03; Pin_Header_Straight_1x03_Pitch2.54mm
J401: DB9_Male; DB9MC
J501: Conn_01x06; Pin_Header_Straight_1x06_Pitch2.54mm
J502, J503, J504: Conn_01x08; Pin_Header_Straight_1x08_Pitch2.54mm
J601: Conn_02x08_Odd_Even; IDC_Header_Straight_16pins
J701: Conn_02x23_Row_Letter_First; Pin_Header_Straight_2x23_Pitch2.54mm
J702, J703: Conn_01x09; Pin_Header_Straight_1x09_Pitch2.54mm
R301, R504: 1K; R_Axial_DIN0204_L3.6mm_D1.6mm_P7.62mm_Horizontal
R302, R501, R502, R503: 4K7; R_Axial_DIN0204_L3.6mm_D1.6mm_P7.62mm_Horizontal
R303: 100R; R_Axial_DIN0204_L3.6mm_D1.6mm_P7.62mm_Horizontal
R401: 10K; R_Axial_DIN0204_L3.6mm_D1.6mm_P7.62mm_Horizontal
TR401, TR402, TR403, TR404, TR405: 2N3904; TO-92_Molded_Narrow

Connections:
+3V3: C302.1, IC301.3 (OUT), IC302.2 (3V3), IC303.2 (VO)
+5V: C303.1, C501.1, IC303.3 (VI), IC501.40 (vcc), IC502.20 (VCC), IC503.4 (vcc), IC801.4 (VCC), J301.1, J504.1, J601.2, J701.b1, R401.1; also elsewhere on the board
+9V: C301.1, IC301.1 (IN), J701.b2; also elsewhere on the board
A0: IC502.2 (I2), J701.b7; also elsewhere on the board
A0': J703.1; also elsewhere on the board
A1: IC502.3 (I3), J701.b8; also elsewhere on the board
A1': J703.2; also elsewhere on the board
A2: IC502.4 (I4), J701.b9; also elsewhere on the board
A2': J703.3; also elsewhere on the board
A3: IC502.5 (I5), J701.b10; also elsewhere on the board
A3': J703.4; also elsewhere on the board
A4: IC502.6 (I6), J701.b22; also elsewhere on the board
A4': J703.5; also elsewhere on the board
A5: J701.b21; also elsewhere on the board
A5': J703.6; also elsewhere on the board
A6: J701.b20; also elsewhere on the board
A6': J703.7; also elsewhere on the board
A7: IC502.7 (I7), IC503.3 (A0), J701.b19; also elsewhere on the board
A7': J703.8; also elsewhere on the board
A8: J701.b18; also elsewhere on the board
A8': J703.9; also elsewhere on the board
A9: J701.b17; also elsewhere on the board
A10: J701.b16; also elsewhere on the board
A11: J701.b15; also elsewhere on the board
A12: J701.b14; also elsewhere on the board
A13: J701.b13; also elsewhere on the board
A14: IC801.1 (A18), IC801.2 (A16), J701.b12; also elsewhere on the board
A15: IC502.11 (I10/~OE~), IC801.3 (A15), J701.b11; also elsewhere on the board
BUSAK: J701.a18; also elsewhere on the board
BUSRQ: J701.a20; also elsewhere on the board
CLK: J701.b6; also elsewhere on the board
D0: J702.2; also elsewhere on the board
D0': IC501.37 (D0), IC503.16 (D0), J701.a4; also elsewhere on the board
D1: J702.3; also elsewhere on the board
D1': IC501.36 (D1), IC503.15 (D1), J701.a5; also elsewhere on the board
D2: J702.4; also elsewhere on the board
D2': IC501.35 (D2), IC503.14 (D2), J701.a6; also elsewhere on the board
D3: J702.5; also elsewhere on the board
D3': IC501.34 (D3), IC503.13 (D3), J701.a9; also elsewhere on the board
D4: J702.6; also elsewhere on the board
D4': IC501.33 (D4), IC503.12 (D4), J701.a10; also elsewhere on the board
D5: J702.7; also elsewhere on the board
D5': IC501.32 (D5), IC503.11 (D5), J701.a8; also elsewhere on the board
D6: J702.8; also elsewhere on the board
D6': IC501.31 (D6), IC503.10 (D6), J701.a7; also elsewhere on the board
D7: J702.9; also elsewhere on the board
D7': IC501.30 (D7), IC503.9 (D7), J701.a1; also elsewhere on the board
EAR_IN: R303.1; also elsewhere on the board
GND: C301.2, C302.2, C303.2, C501.2, IC301.2 (GND), IC302.1 (GND), IC302.15 (GND), IC302.38 (GND), IC302.39 (GND-PAD), IC303.1 (GND), IC501.1 (GND), IC502.10 (GND), IC503.6 (GND), J301.4, J302.3, J504.8, J601.4, J701.b4, J701.b5, J702.1, R302.2, R504.2; also elsewhere on the board
HALT: J701.a13; also elsewhere on the board
INT: J701.a11; also elsewhere on the board
IO22: IC302.36 (IO22), J301.3, R303.2
IORQ: IC502.9 (I9), J701.a15; also elsewhere on the board
KBD0: J601.8, TR404.3 (C); also elsewhere on the board
KBD1: J601.10; also elsewhere on the board
KBD2: J601.12, TR401.3 (C); also elsewhere on the board
KBD3: J601.14, TR405.3 (C); also elsewhere on the board
KBD4: J601.16, TR402.3 (C), TR403.3 (C); also elsewhere on the board
MI: J701.a22; also elsewhere on the board
MREQ: IC502.1 (I1/CLK), J701.a14; also elsewhere on the board
NMI: J701.a12; also elsewhere on the board
unnamed: IC302.34 (RXD0), J302.2
unnamed: IC302.35 (TXD0), J302.1
unnamed: IC501.3 (CHN_A), IC503.5 (SO), R501.2
unnamed: IC501.4 (CHN_B), R502.2
unnamed: IC501.6 (IOB7), J503.8
unnamed: IC501.7 (IOB6), J503.7
unnamed: IC501.8 (IOB5), J503.6
unnamed: IC501.9 (IOB4), J503.5
unnamed: IC501.10 (IOB3), J503.4
unnamed: IC501.11 (IOB2), J503.3
unnamed: IC501.12 (IOB1), J503.2
unnamed: IC501.13 (IOB0), J503.1
unnamed: IC501.14 (IOA7), J502.8
unnamed: IC501.15 (IOA6), J502.7
unnamed: IC501.16 (IOA5), J502.6
unnamed: IC501.17 (IOA4), J502.5
unnamed: IC501.18 (IOA3), J502.4
unnamed: IC501.19 (IOA2), J502.3
unnamed: IC501.20 (IOA1), J502.2
unnamed: IC501.21 (IOA0), J502.1
unnamed: IC501.22 (CLOCK), IC503.7 (CLOCK), J504.7
unnamed: IC501.23 (~RESET), IC503.8 (~RESET), J504.6
unnamed: IC501.24 (~A9), J504.5
unnamed: IC501.25 (A8), J504.4
unnamed: IC501.26 (~SEL), J504.3
unnamed: IC501.27 (BDIR), IC502.19 (IO1), IC503.2 (~CS)
unnamed: IC501.28 (BC2), J504.2
unnamed: IC501.29 (BC1), IC502.18 (IO2)
unnamed: IC501.38 (CHN_C), R503.2
unnamed: IC502.12 (IO8), J501.6
unnamed: IC502.13 (IO7), J501.5
unnamed: IC502.14 (IO6), J501.4
unnamed: IC502.15 (IO5), J501.3
unnamed: IC502.16 (IO4), J501.2
unnamed: IC502.17 (I03), J501.1
unnamed: J401.1, TR405.2 (B)
unnamed: J401.2, TR403.2 (B)
unnamed: J401.3, TR402.2 (B)
unnamed: J401.4, TR401.2 (B)
unnamed: J401.6, TR404.2 (B)
unnamed: J401.8, R401.2
RAM_CS: J701.a2; also elsewhere on the board
RD: J701.a16; also elsewhere on the board
RESET: J701.a21; also elsewhere on the board
RFSH: J701.a23; also elsewhere on the board
ROM_CS: J701.b23; also elsewhere on the board
ROW1: J601.9, TR402.1 (E); also elsewhere on the board
ROW2: J601.11; also elsewhere on the board
ROW3: J601.7; also elsewhere on the board
ROW4: J601.13, TR401.1 (E), TR403.1 (E), TR404.1 (E), TR405.1 (E); also elsewhere on the board
ROW5: J601.5; also elsewhere on the board
ROW6: J601.15; also elsewhere on the board
ROW7: J601.3; also elsewhere on the board
ROW8: J601.1; also elsewhere on the board
SOUND: R501.1, R502.1, R503.1, R504.1; also elsewhere on the board
TAPE_OUT: R301.1; also elsewhere on the board
VP: IC302.4 (SENSOR_VP), J301.2, R301.2, R302.1
WAIT: J701.a19; also elsewhere on the board
WR: IC502.8 (I8), IC503.1 (~WR), J701.a17; also elsewhere on the board

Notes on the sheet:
RIGHT
LEFT
DOWN
FIRE
dK'tronics KEYBOARD

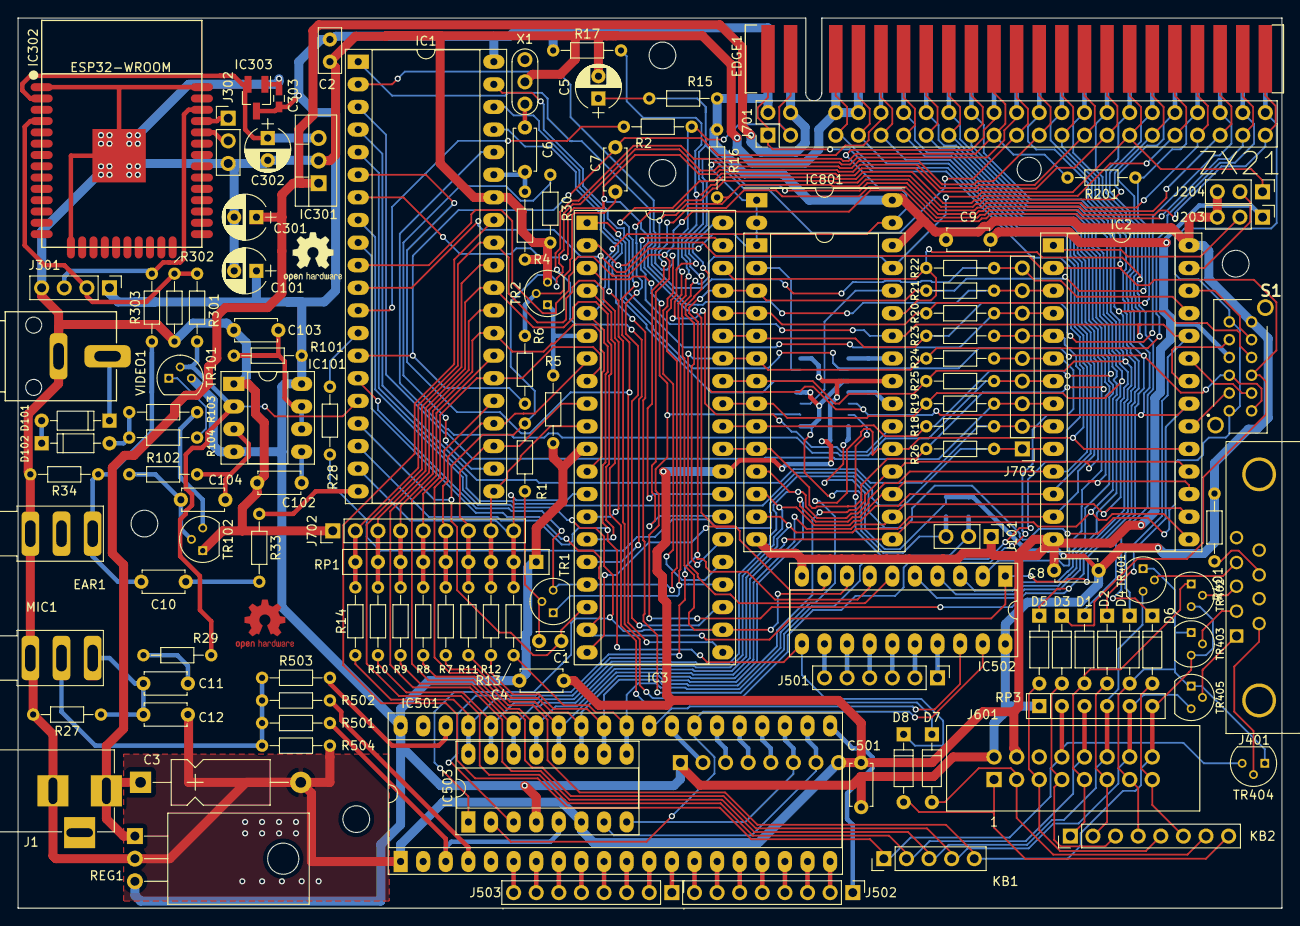
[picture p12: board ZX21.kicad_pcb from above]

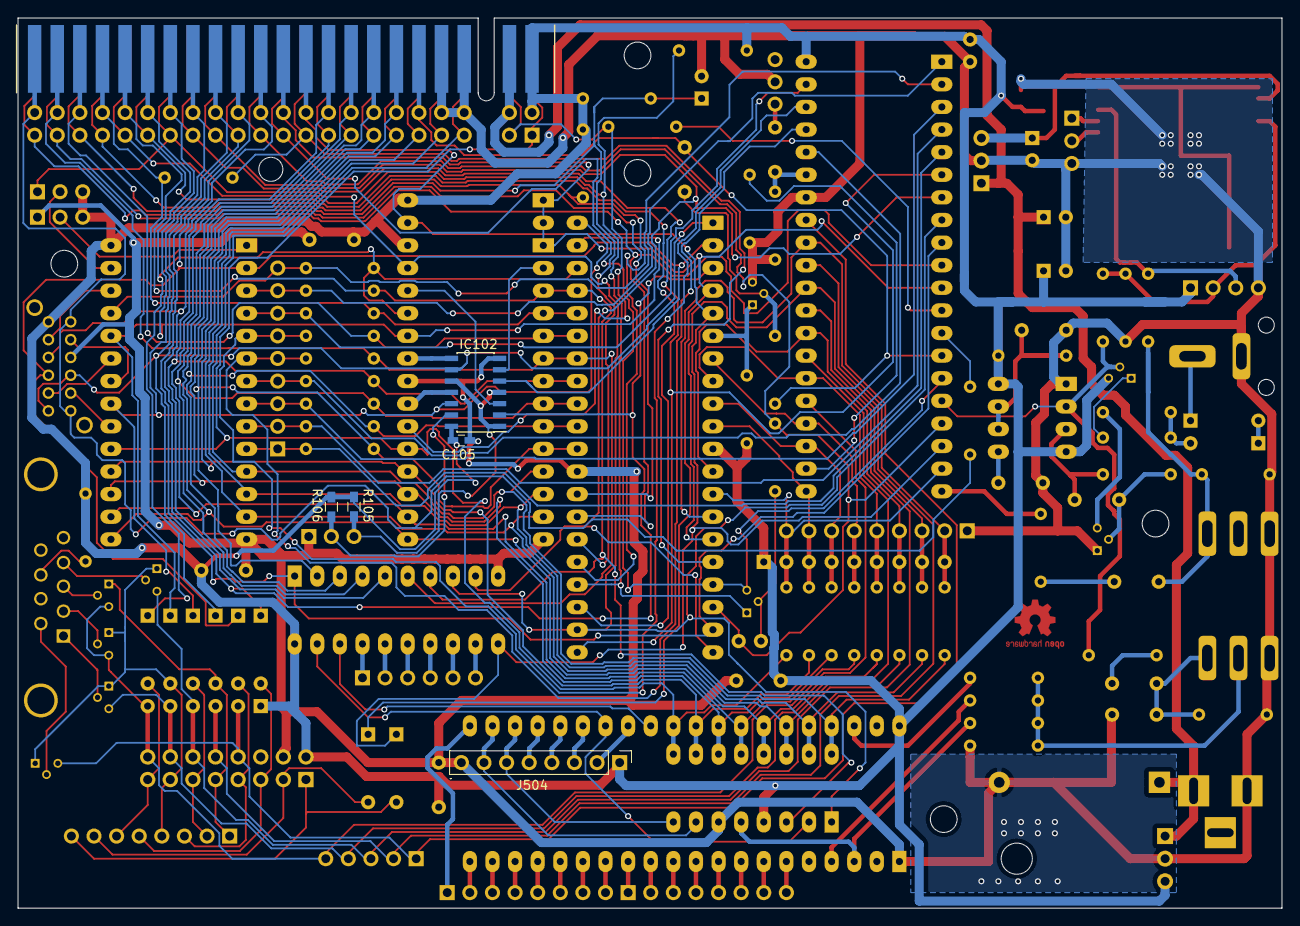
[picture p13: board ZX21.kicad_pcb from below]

Board: 2 copper layers, 142.0 x 100.0 mm, 125 parts (5 on the bottom side), 153 nets.

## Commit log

2020-11-24 Main Sheet complete
    [ZX21.sch]
2020-11-24 Start Extras
    [ESP32-Footprints.kicad_pcb, ESP32-Footprints.sch, ZX21.sch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]
2020-11-25 Extras first draft
    [ZX21.sch, ZX21_Extras.sch]
2020-11-25 Fixed most ERC Issues
    [ZX21.sch, ZX21_Extras.sch]
2020-11-26 Layout Started
    [ZX21.sch, ZX21_Extras.sch]
2020-11-26 Diodes fixed
    [ZX21.kicad_pcb, ZX21.sch]
2020-11-26 Added mounring holes
    [ZX21.kicad_pcb, ZX21.sch, ZX21_Extras.sch]
2020-11-26 Placement getting there
    [ZX21.kicad_pcb, ZX21_Extras.sch]
2020-11-27 Add Gate
    [ZX21.kicad_pcb, ZX21.sch]
2020-11-27 Part way through routing
    [ZX21.kicad_pcb, ZX21.sch, ZX21_Extras.sch]
2020-11-28 Yet more routing!
    [ZX21.kicad_pcb]
2020-11-28 Even more routing
    [ZX21.kicad_pcb, ZX21.sch]
2020-11-28 3 SD working better
    [ZX21.kicad_pcb, ZX21.sch, ZX21_Extras.sch]
2020-11-29 Yup more routing
    [ZX21.kicad_pcb, ZX21.sch, ZX21_Extras.sch]
2020-11-30 Added option for YMZ284 :D
    [ZX21.kicad_pcb, ZX21_Extras.sch]
2020-12-01 Tidy Up
    [ZX21.kicad_pcb]
2020-12-01 Into DRC
    [ZX21.kicad_pcb]
2020-12-02 Fixing DRC Issues
    [ZX21.kicad_pcb, ZX21.sch, ZX21_Extras.sch]
2020-12-04 FIrst go at DRC complete
    [ZX21.kicad_pcb, ZX21.sch, ZX21_Extras.sch]
2020-12-05 ESP32 Flipped
    [ZX21.kicad_pcb, ZX21.sch, ZX21_Extras.sch]
2020-12-05 Gerbers made
    [ZX21-B_Cu.gbl, ZX21-B_Mask.gbs, ZX21-B_Paste.gbp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]
2020-12-11 Try to push interactive bom
    [ZX21.csv, ZX21_2.csv, ZX21_2.ods]

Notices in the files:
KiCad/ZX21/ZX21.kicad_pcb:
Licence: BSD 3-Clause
